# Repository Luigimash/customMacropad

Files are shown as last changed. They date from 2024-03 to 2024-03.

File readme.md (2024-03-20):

# Custom Macropad

A completely custom-built customizable macropad I built as a gift for a friend. Completed officially on March 11 2024.

Features:
- 3D printed enclosure
- Laser cut 1.5mm acrylic plate
- Custom PCB 
- QMK VIAL firmware 

All of my design files are collected within this repository. Some other items that you may need to purchase to complete this build:
- Standard Mechanical Keyboard Switches with a CherryMX footprint (used Wuque Studio Browns)
- SEED XIAO RP2040 Microcontroller
- 1N4148 Small Signal Switching Diodes
- EC11 (used Alps EC11E15244B2-ND)

Some tools I used:
- 3D Printers
- Laser Cutters
- AutoCAD for designing the acrylic plate
- Solidworks for designing the enclosure
- KiCAD for the circuit schematic and PCB gerbers

## Gallery
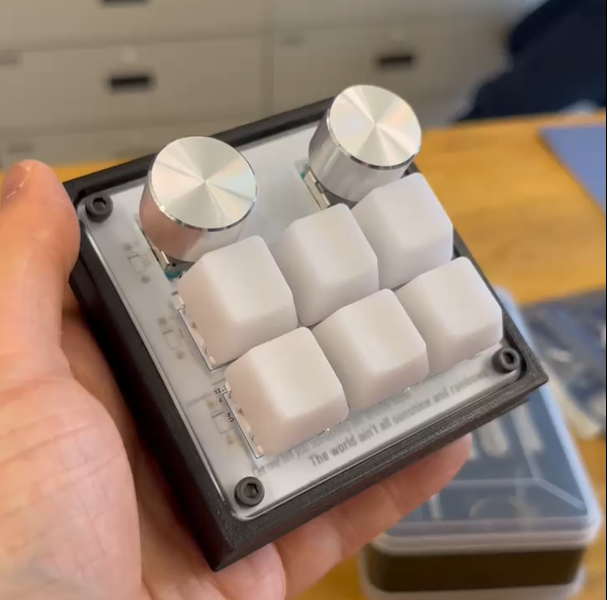
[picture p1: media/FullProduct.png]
Full Product

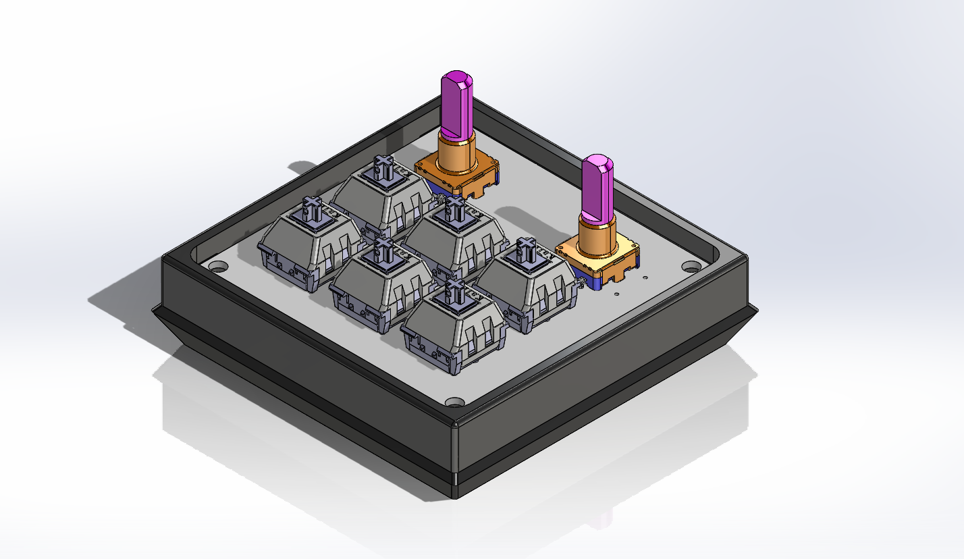
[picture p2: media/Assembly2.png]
Image of Solidworks Assembly 1

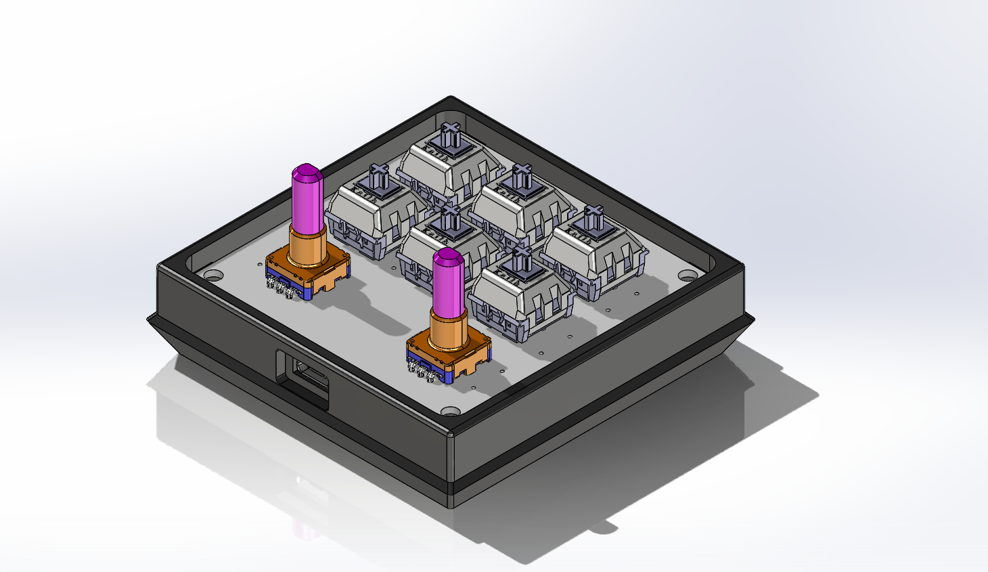
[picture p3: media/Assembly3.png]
Image of Solidworks Assembly 2

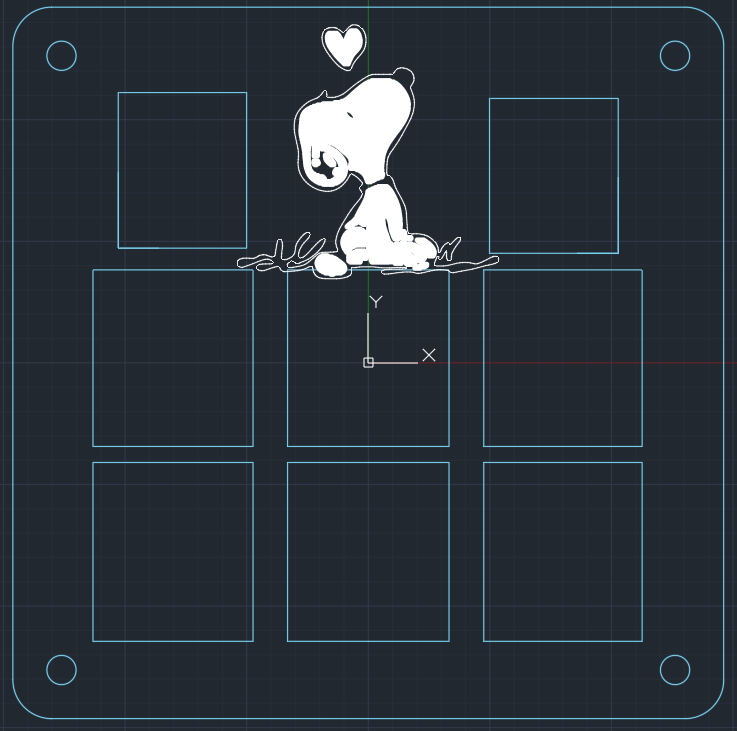
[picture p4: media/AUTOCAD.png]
AutoCAD Plate

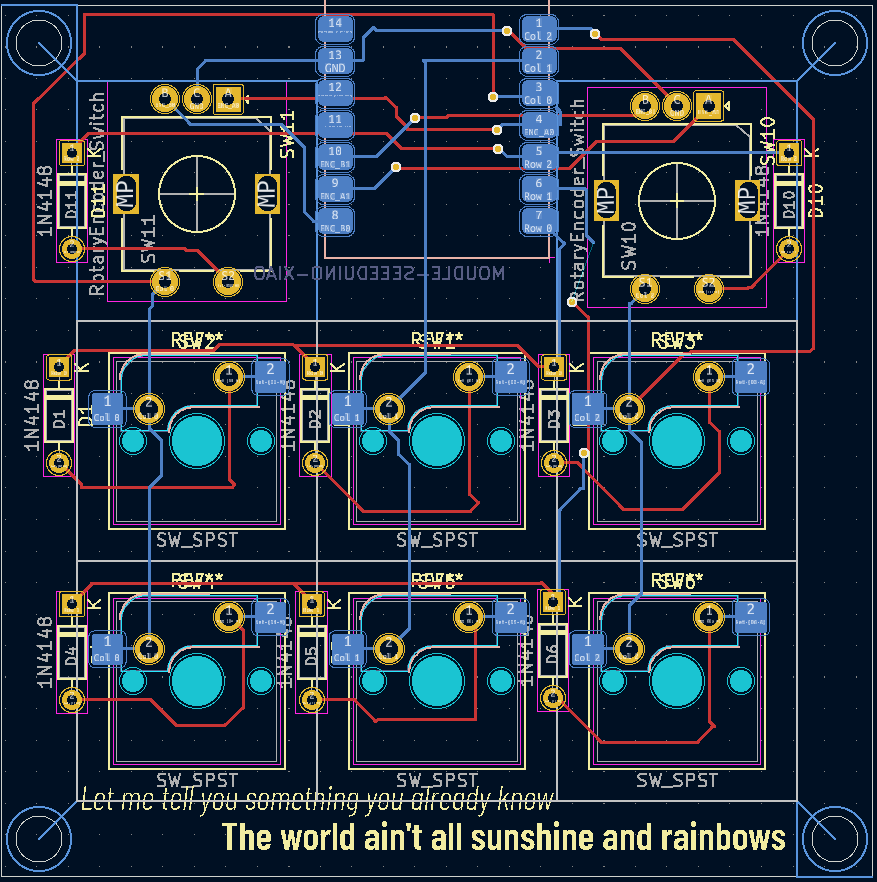
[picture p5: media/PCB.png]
PCB in KiCAD

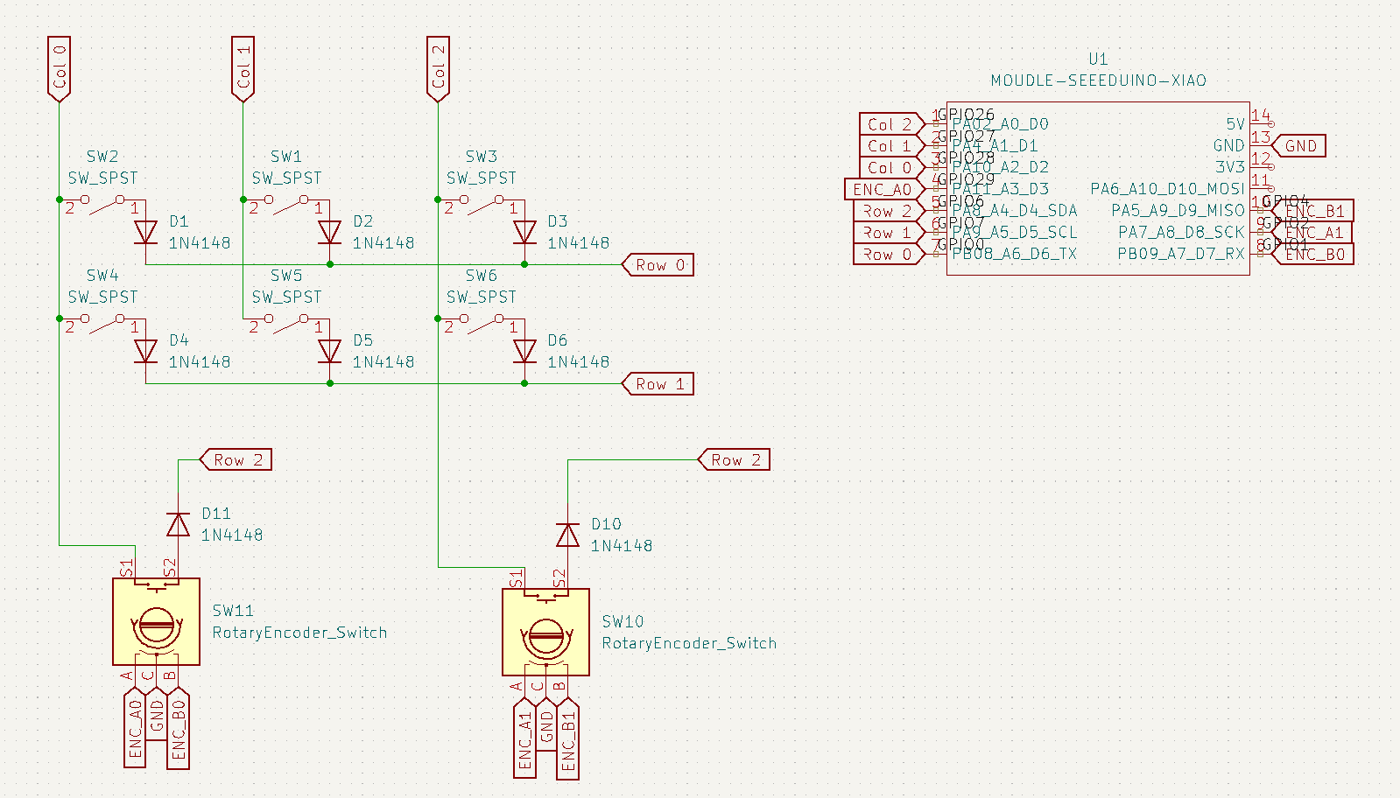
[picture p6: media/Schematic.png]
KiCAD Schematic


## Next Steps
- The rotary encoders are WAY too close to the keycaps, making it difficult to rotate (although it does thankfully actually rotate). They should be moved such that they are placed further away from the keycaps by at least 5mm or so.

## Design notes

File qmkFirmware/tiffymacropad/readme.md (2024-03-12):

# tiffymacropad

tiffymacropad

*A short description of the keyboard/project*

* Keyboard Maintainer: [TODO](https://github.com/TODO)
* Hardware Supported: *The PCBs, controllers supported*
* Hardware Availability: *Links to where you can find this hardware*

Make example for this keyboard (after setting up your build environment):

    make tiffymacropad:default

Flashing example for this keyboard:

    make tiffymacropad:default:flash

See the [build environment setup](https://docs.qmk.fm/#/getting_started_build_tools) and the [make instructions](https://docs.qmk.fm/#/getting_started_make_guide) for more information. Brand new to QMK? Start with our [Complete Newbs Guide](https://docs.qmk.fm/#/newbs).

## Bootloader

Enter the bootloader in 3 ways:

* **Bootmagic reset**: Hold down the key at (0,0) in the matrix (usually the top left key or Escape) and plug in the keyboard
* **Physical reset button**: Briefly press the button on the back of the PCB - some may have pads you must short instead
* **Keycode in layout**: Press the key mapped to `QK_BOOT` if it is available

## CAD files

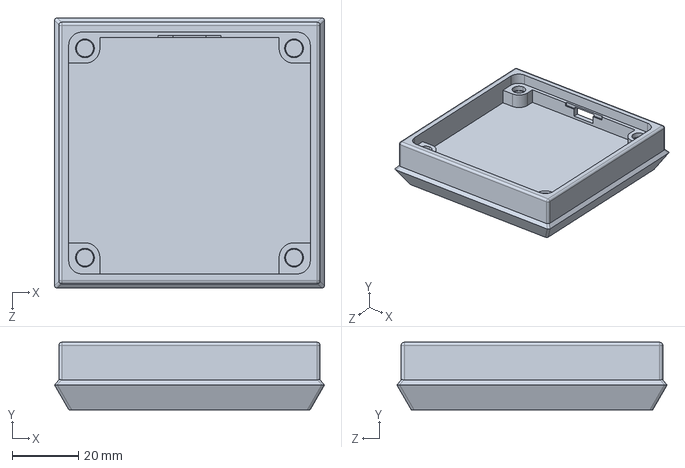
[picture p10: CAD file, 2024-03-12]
Macropad_Enclosure.STEP
81.5 x 20.4 x 81.5 mm

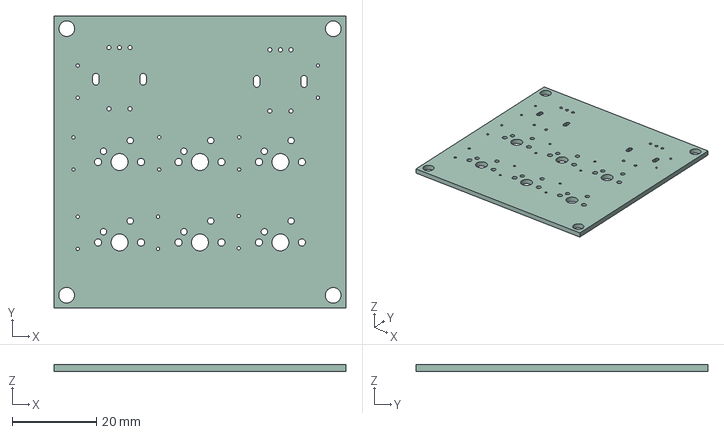
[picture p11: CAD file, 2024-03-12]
MacropadPCB/MacropadPCB.step
69.1 x 69.1 x 1.60 mm

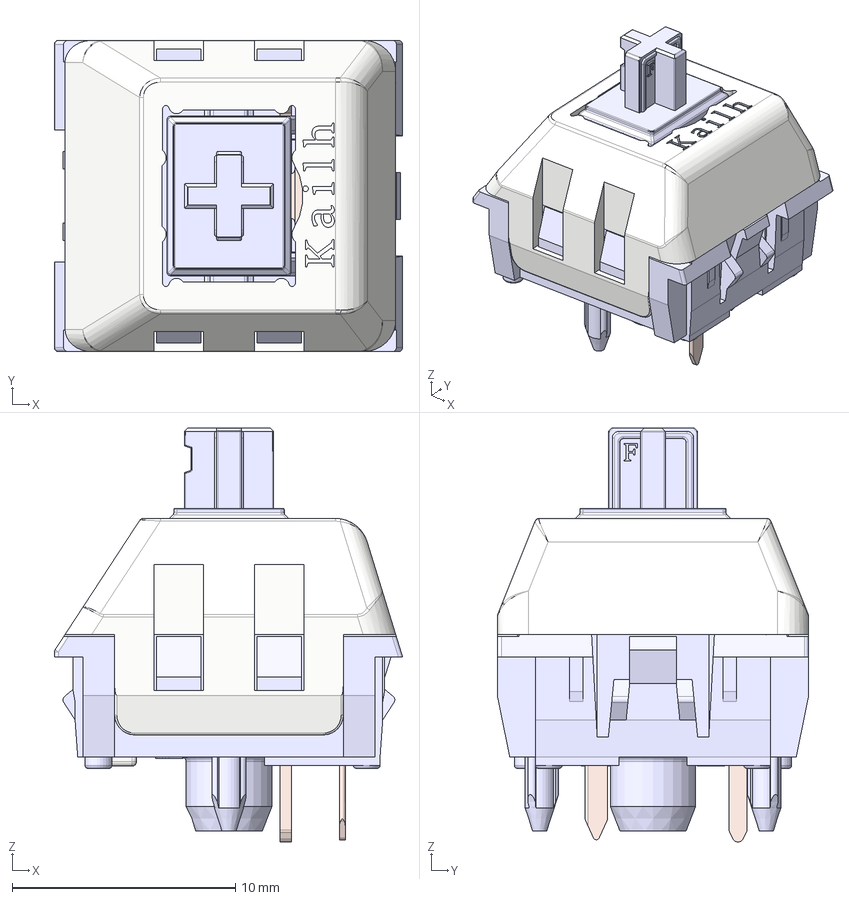
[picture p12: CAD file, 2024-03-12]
Kailh Polia.step
15.6 x 14.0 x 18.5 mm
Housing
ThickContact
SpringContact
Stem
Lid

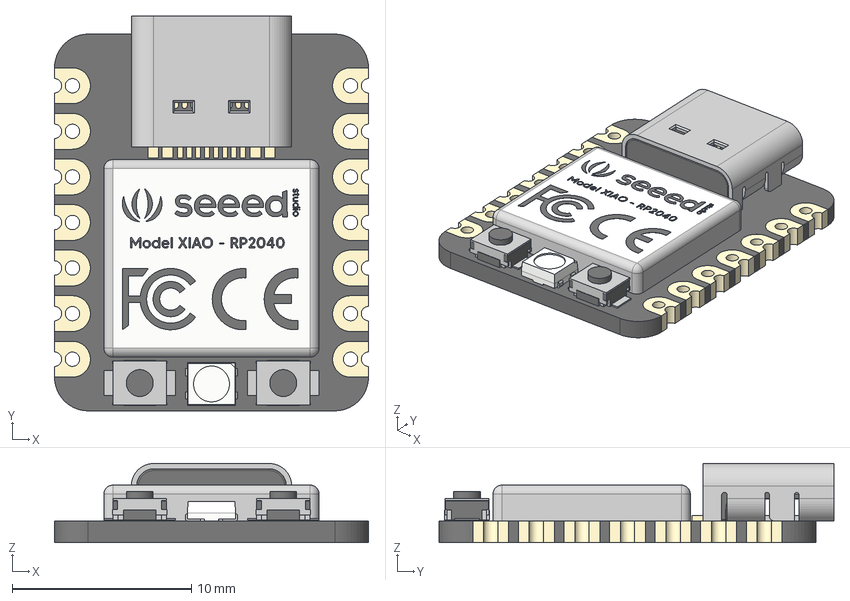
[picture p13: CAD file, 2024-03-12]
Seeed Studio XIAO RP2040 v26.step
17.5 x 22.0 x 4.40 mm
type-c v2
smd_button v3
DOUT
DIN
VSS
VDD
smd_button v3(Mirror)

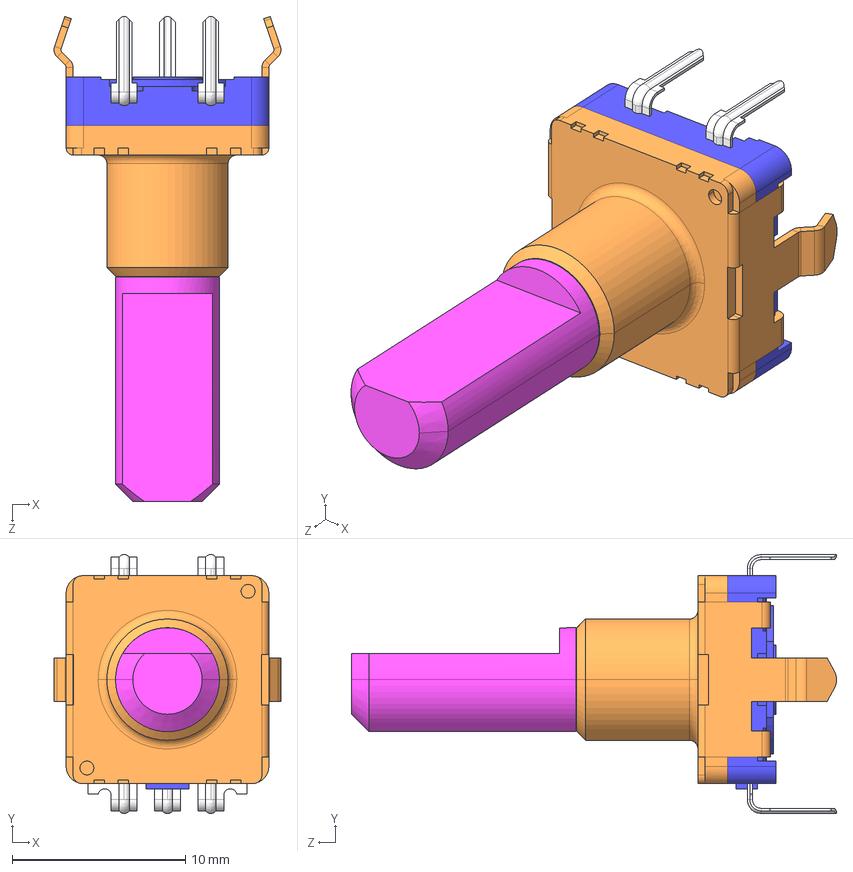
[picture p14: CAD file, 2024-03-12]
EC11E-nonSW.STEP
13.1 x 15.0 x 28.0 mm

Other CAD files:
planningDesign.dwg
acrylicFaceplate_2.dwg
Macropad_Enclosure.SLDPRT

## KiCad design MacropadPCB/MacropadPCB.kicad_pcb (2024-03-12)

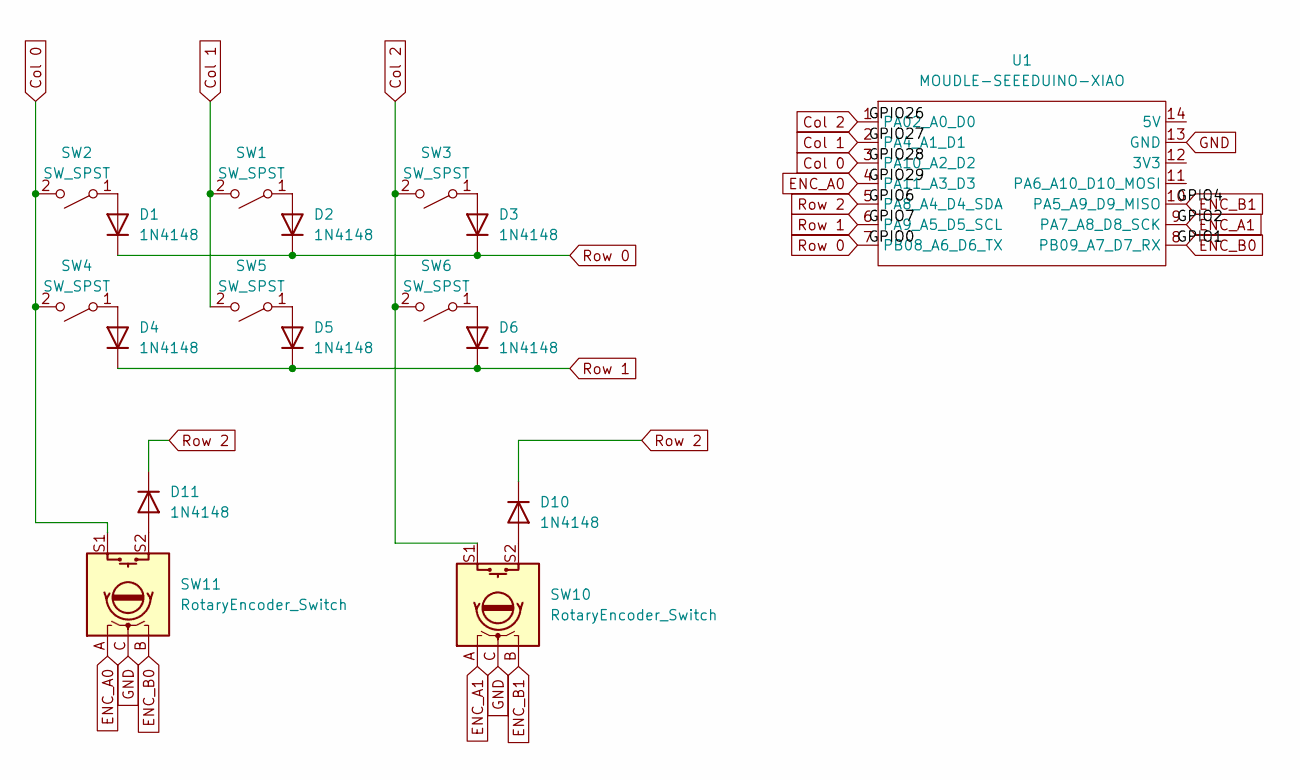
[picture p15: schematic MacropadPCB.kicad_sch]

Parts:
D1, D2, D3, D4, D5, D6, D10, D11: 1N4148; D_DO-35_SOD27_P7.62mm_Horizontal
SW1, SW2, SW3, SW4, SW5, SW6: SW_SPST; SW_Cherry_MX_1.00u_PCB
SW10, SW11: RotaryEncoder_Switch; RotaryEncoder_Alps_EC11E-Switch_Vertical_H20mm
U1: MOUDLE-SEEEDUINO-XIAO; MOUDLE14P-SMD-2.54-21X17.8MM

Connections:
Col 0: SW2.2 (B), SW4.2 (B), SW11.S1, U1.3 (PA10_A2_D2)
Col 1: SW1.2 (B), SW5.2 (B), U1.2 (PA4_A1_D1)
Col 2: SW3.2 (B), SW6.2 (B), SW10.S1, U1.1 (PA02_A0_D0)
ENC_A0: SW11.A, U1.4 (PA11_A3_D3)
ENC_A1: SW10.A, U1.9 (PA7_A8_D8_SCK)
ENC_B0: SW11.B, U1.8 (PB09_A7_D7_RX)
ENC_B1: SW10.B, U1.10 (PA5_A9_D9_MISO)
GND: SW10.C, SW11.C, U1.13 (GND)
unnamed: D1.2 (A), SW2.1 (A)
unnamed: D2.2 (A), SW1.1 (A)
unnamed: D3.2 (A), SW3.1 (A)
unnamed: D4.2 (A), SW4.1 (A)
unnamed: D5.2 (A), SW5.1 (A)
unnamed: D6.2 (A), SW6.1 (A)
unnamed: D10.2 (A), SW10.S2
unnamed: D11.2 (A), SW11.S2
Row 0: D1.1 (K), D2.1 (K), D3.1 (K), U1.7 (PB08_A6_D6_TX)
Row 1: D4.1 (K), D5.1 (K), D6.1 (K), U1.6 (PA9_A5_D5_SCL)
Row 2: D10.1 (K), D11.1 (K), U1.5 (PA8_A4_D4_SDA)

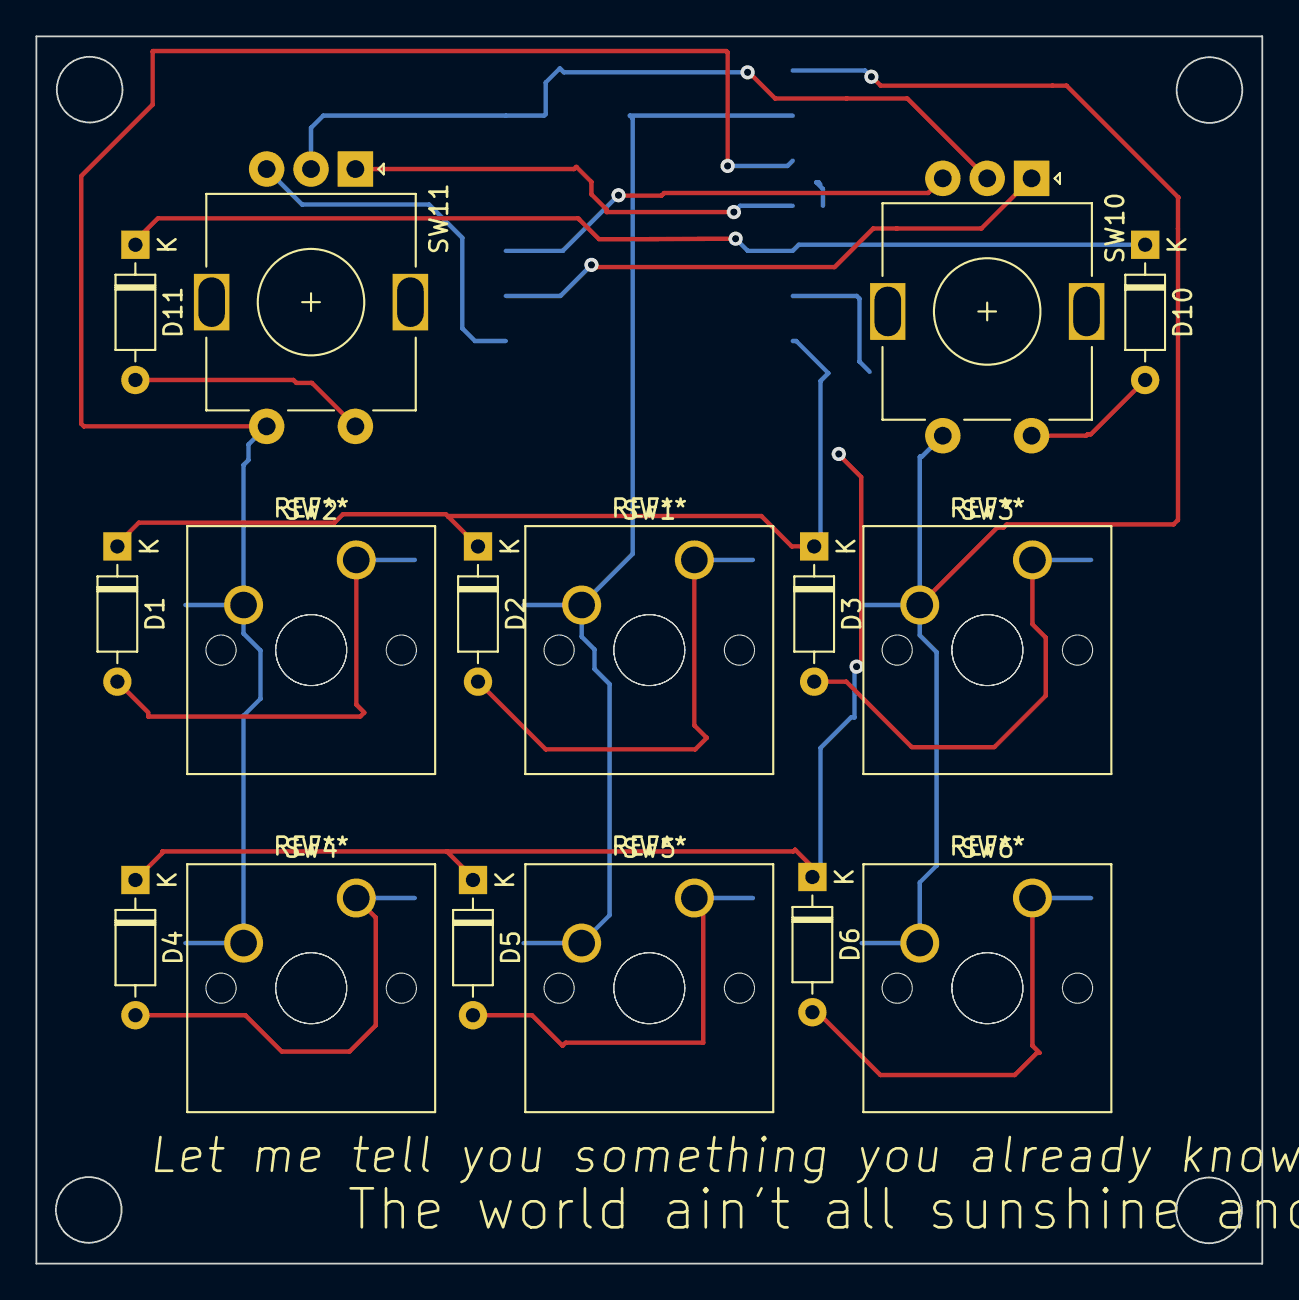
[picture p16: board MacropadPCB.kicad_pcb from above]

Board: 2 copper layers, 69.1 x 69.1 mm, 17 parts (1 on the bottom side), 19 nets.

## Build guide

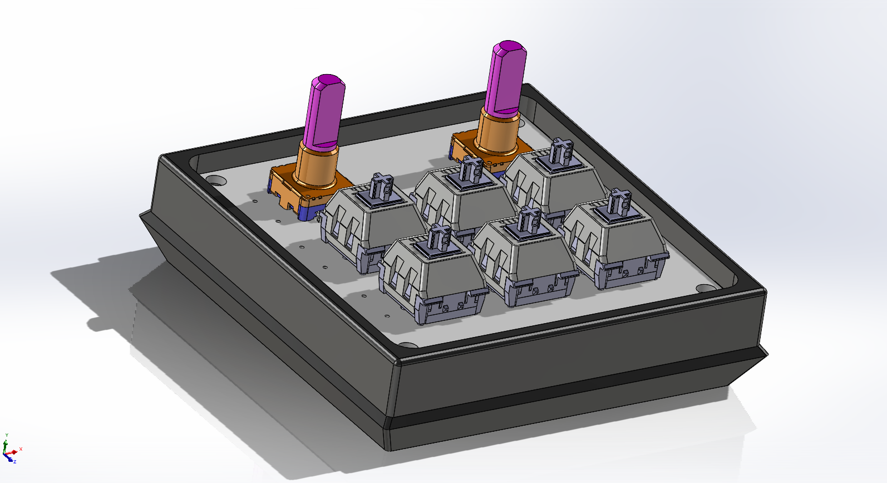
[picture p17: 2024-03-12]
media/Assembly1.png

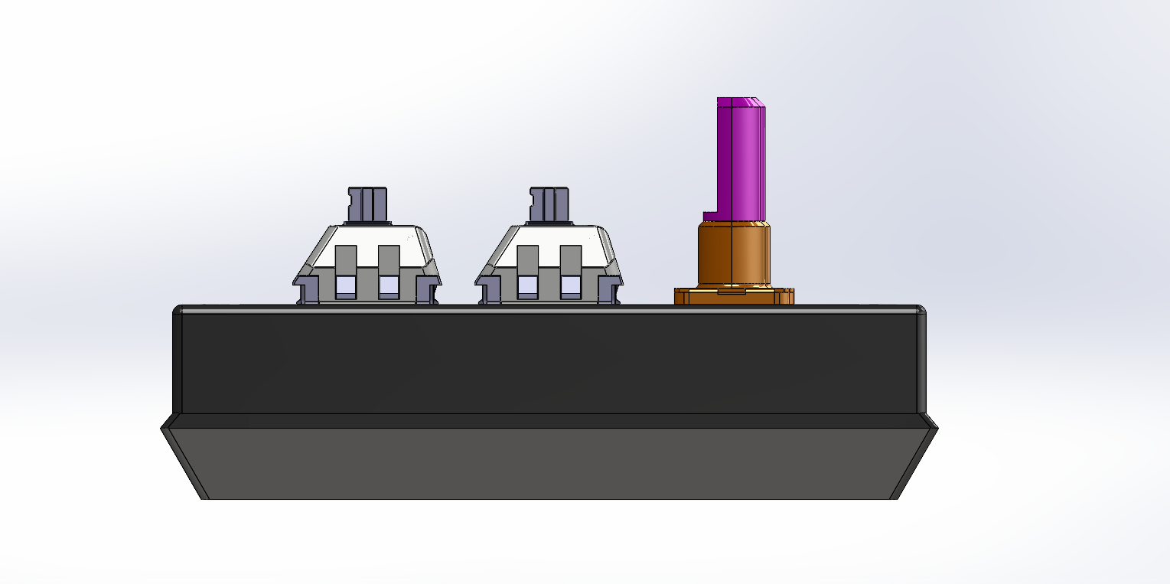
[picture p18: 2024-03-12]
media/Assembly5.png

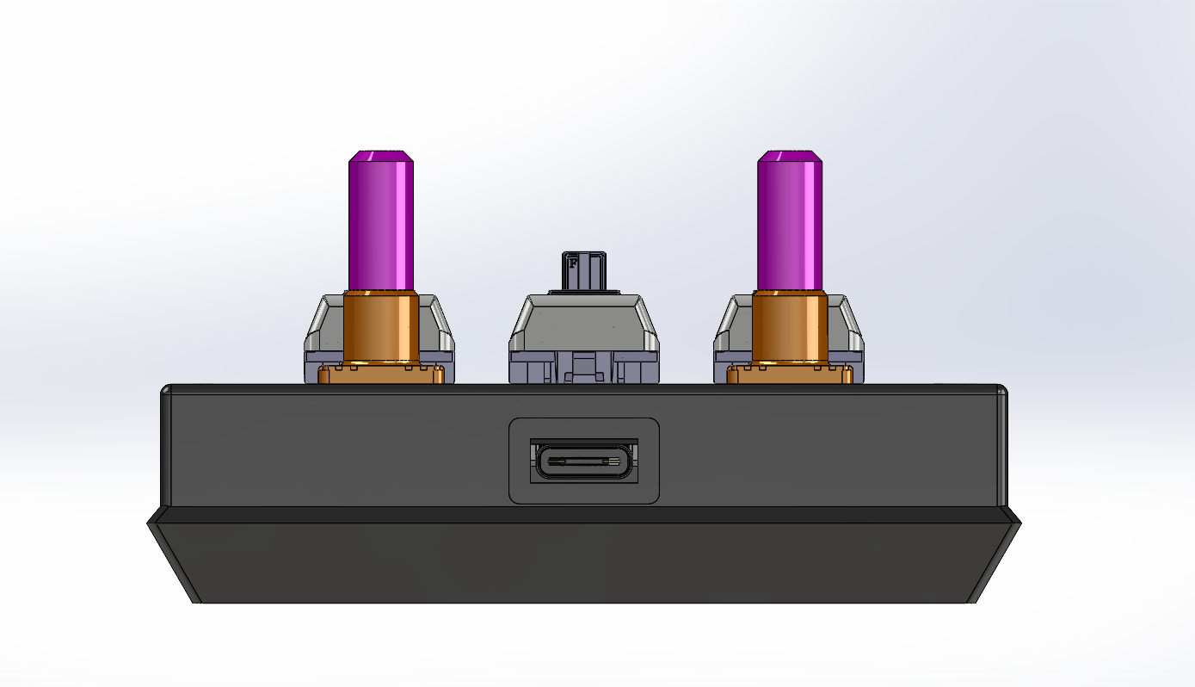
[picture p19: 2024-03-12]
media/Assembly4.png
